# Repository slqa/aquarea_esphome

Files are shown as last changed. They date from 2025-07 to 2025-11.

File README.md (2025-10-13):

# Description
This project allows for controlling Aquarea F-series heat pumps directly from Home Assistant via standard ESPHome controls.
For it to function, special hardware is needed, which you will have to place between the remote control and the heat pump.
Thanks to this device, you are able to monitor heat pump states and issue your own commands.

```
  Heatpump RX ------|---|---/---------TX  REMOTE
           TX ------|   |   |         RX
            |       |   |   |         |
            |      RX  TX  RTS        |
            |      ESP12E             |
            |-------------------------|
```
I used hardware serial on pins GPIO15/GPIO13 and one pin for RTS from a GPIO5 Mini ESP board. In a 'normal' situation, the ESP12E only listens to communication between the remote and the heat pump, so you can have entity updates.
When you want to issue a state change from Home Assistant, the RTS pin is set, blocking communication from the remote to the heat pump. The ESP12E then sends the command and waits for confirmation.
After sending commands, it returns to the 'normal' state.
The Panasonic UART protocol has a baud_rate of 960, data_bits of 8, stop_bits of 1, parity of EVEN, and is inverted. My version of the bridge device realizes inversion at the hardware level, so there is no such setting in the YAML UART configuration.

Bridge PCB using ESP12E:
Brige schematic schematic

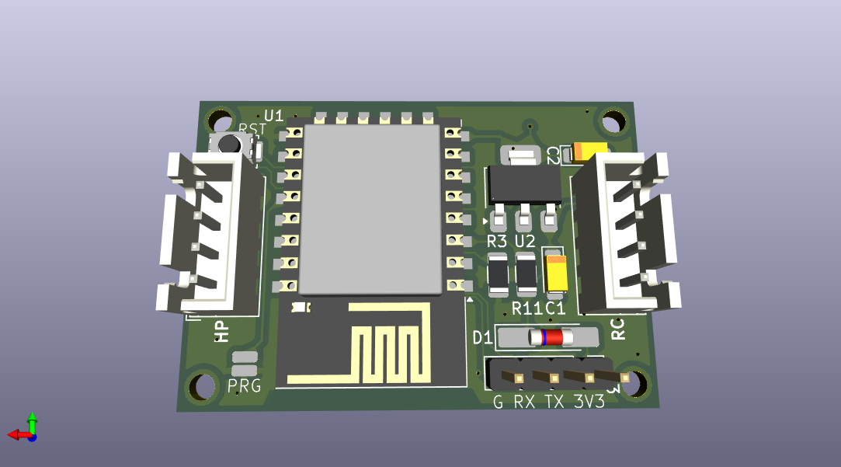
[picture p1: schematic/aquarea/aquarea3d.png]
Brige view view

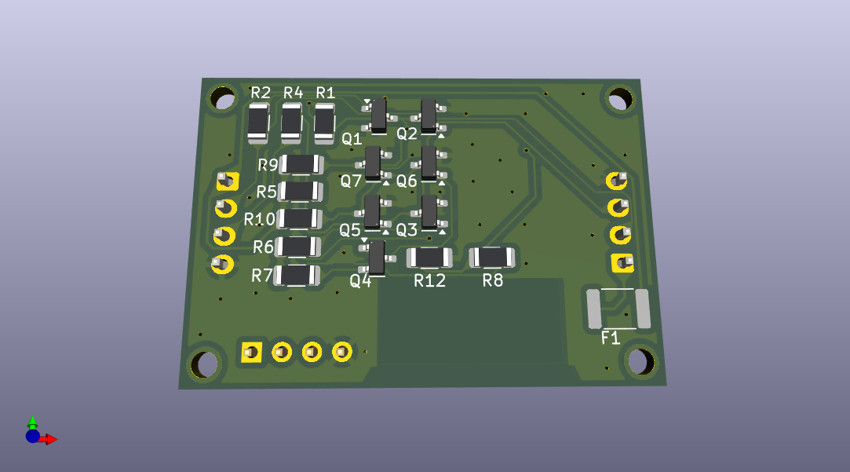
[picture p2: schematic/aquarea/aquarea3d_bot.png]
Brige view view_bottom


# How to use
Follow normal ESPHome steps
```bash
docker pull ghcr.io/esphome/esphome
docker run --rm -v "${PWD}":/config -it ghcr.io/esphome/esphome compile aquarea.yaml
docker run --rm -v "${PWD}":/config -it ghcr.io/esphome/esphome run aquarea.yaml
```

## 💾 Flashing Firmware via UART

Follow these steps to successfully flash your device's firmware using a UART adapter.

### 1. Wiring and Connection

Connect your **UART adapter** (or an ESP board with a USB level shifter) to the board's gold pin connector using the following pins:

| Pin | Function | Adapter Connection |
| :--- | :--- | :--- |
| **3.3V** | Power | Connect to **3.3V** on the adapter. |
| **TX** | Transmit | Connect to **RX** on the adapter. |
| **RX** | Receive | Connect to **TX** on the adapter. |
| **Gnd** | Ground | Connect to **Gnd** on the adapter. |

> ⚠️ **IMPORTANT:** If the PCB is still powered by the heat pump, **DO NOT CONNECT the 3.3V pin** from your adapter.

---

### 2. Entering Program Mode (Flash Mode)

To put the board into Flash Mode:

1.  **Short the PRG point:** Use a screwdriver or jumper wire to short the **PRG** test point (sometimes marked as old **SW1**).
2.  **Power Cycle:** While the **PRG** point is still shorted, quickly **power cycle** the PCB. You can do this by:
    * Disconnecting and immediately reconnecting the power **3.3V** pin.
    * Unplugging and replugging the main heat pump connector from the PCB.
    * Cycling the main power to the heat pump unit.
3.  **Release Short:** Once the power cycle is complete, **release the short** on the **PRG** point.

The device is now in **Flash Mode** and ready to accept new firmware.
# Home assistant entites

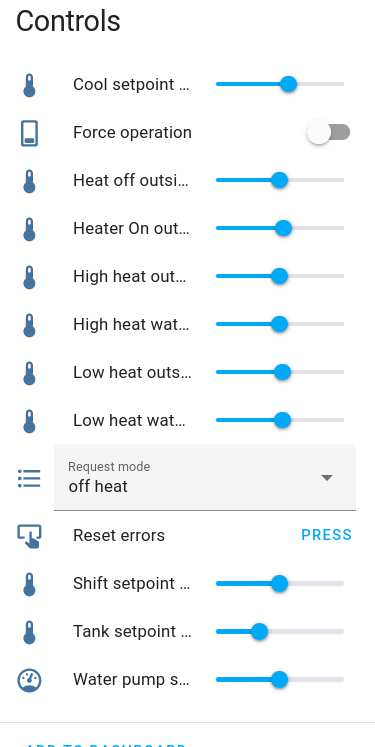
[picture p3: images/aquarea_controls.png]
Aquarea controls HA Controls

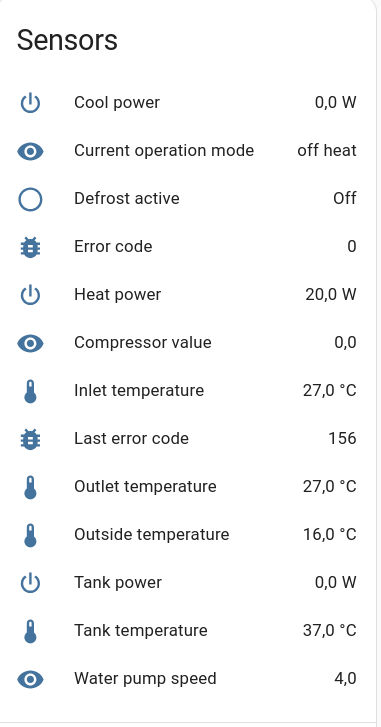
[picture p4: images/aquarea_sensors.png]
Aquarea sensors HA Sensors


# Thank you
Many thanks for work done by<br>
https://github.com/v-s-c-o-p-e/geisha_aquarea_panasonic_arduino_esp8266_proxy
https://github.com/pemue-git/pcb/tree/master/WH-MDC05F3E5_comm

## Disclaimer of Liability

THIS SOFTWARE IS PROVIDED "AS IS", WITHOUT WARRANTY OF ANY KIND, EXPRESS OR IMPLIED, INCLUDING BUT NOT LIMITED TO THE WARRANTIES OF MERCHANTABILITY, FITNESS FOR A PARTICULAR PURPOSE AND NONINFRINGEMENT. IN NO EVENT SHALL THE AUTHORS OR COPYRIGHT HOLDERS BE LIABLE FOR ANY CLAIM, DAMAGES OR OTHER LIABILITY, WHETHER IN AN ACTION OF CONTRACT, TORT OR OTHERWISE, ARISING FROM, OUT OF OR IN CONNECTION WITH THE SOFTWARE OR THE USE OR OTHER DEALINGS IN THE SOFTWARE.

You are solely responsible for any damage to your property, data, or third-party devices that results from the use or misuse of this software. By using this software, you agree to assume all risks associated with its use.

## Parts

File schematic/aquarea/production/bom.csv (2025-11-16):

Designator | Footprint | Quantity | Value | LCSC Part #
C1, C2 | CP_EIA-3216-10_Kemet-I_HandSolder | 2 | 10u
D1 | D_MiniMELF_Handsoldering | 1 | D_Schottky_Small
F1 | 1812 | 1 | 250mA
J1 | JST_XH_B4B-XH-A_1x04_P2.50mm_Vertical | 1 | RC_CABLE
J2 | JST_XH_B4B-XH-A_1x04_P2.50mm_Vertical | 1 | HP_CABLE
J3 | PinHeader_1x04_P2.54mm_Vertical | 1 | ESP_PROG
Q1, Q2, Q3, Q5, Q6, Q7 | SOT-23 | 6 | BC847
Q4 | SOT-23 | 1 | BC857
R1, R11, R3, R4, R6, R7 | 1206 | 6 | 1k
R10, R12, R2, R8, R9 | 1206 | 5 | 10k
R5 | 1206 | 1 | 20k
SW1 | 0508 | 1 | Flash
SW2 | SW_Push_SPST_NO_Alps_SKRK | 1 | RESET
U1 | ESP-12E | 1 | ESP-12E
U2 | SOT-223-3_TabPin2 | 1 | AMS1117-3.3

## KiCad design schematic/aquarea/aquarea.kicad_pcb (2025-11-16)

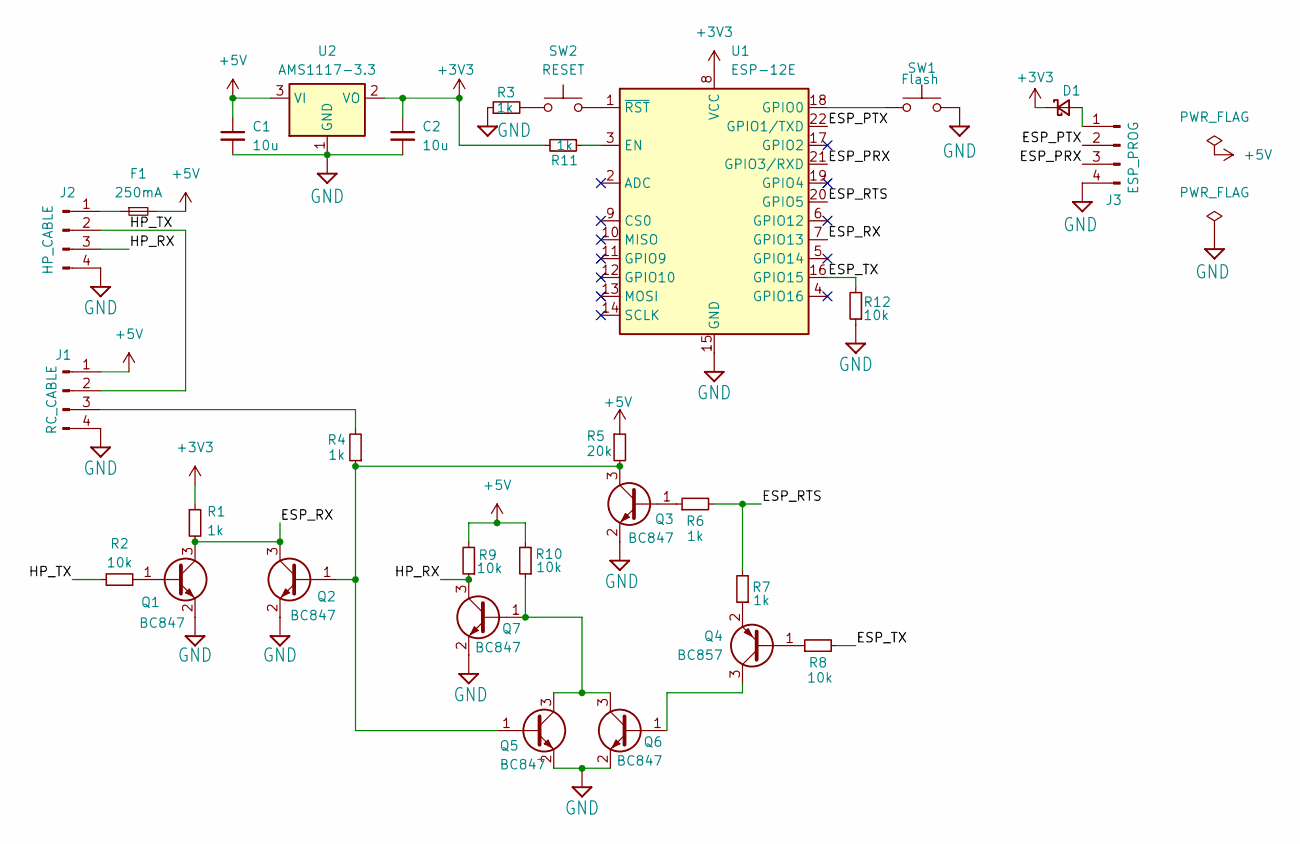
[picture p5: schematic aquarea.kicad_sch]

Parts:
C1, C2: 10u; CP_EIA-3216-10_Kemet-I_HandSolder
D1: D_Schottky_Small; D_MiniMELF_Handsoldering
F1: 250mA; Fuse_1812_4532Metric
J1: RC_CABLE; JST_XH_B4B-XH-A_1x04_P2.50mm_Vertical
J2: HP_CABLE; JST_XH_B4B-XH-A_1x04_P2.50mm_Vertical
J3: ESP_PROG; PinHeader_1x04_P2.54mm_Vertical
Q1, Q2, Q3, Q5, Q6, Q7: BC847; SOT-23
Q4: BC857; SOT-23
R1, R3, R4, R6, R7, R11: 1k; R_1206_3216Metric
R2, R8, R9, R10, R12: 10k; R_1206_3216Metric
R5: 20k; R_1206_3216Metric
SW1: Flash; R_0508_1220Metric
SW2: RESET; SW_Push_SPST_NO_Alps_SKRK
U1: ESP-12E
U2: AMS1117-3.3; SOT-223-3_TabPin2

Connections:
+3V3: C2.1, D1.1 (K), R1.1, R11.2, U1.8 (VCC), U2.2 (VO)
+5V: C1.1, F1.2, J1.1, R5.1, R9.2, R10.2, U2.3 (VI)
/ESP_PRX: J3.3, U1.21 (GPIO3/RXD)
/ESP_PTX: J3.2, U1.22 (GPIO1/TXD)
/ESP_RTS: R6.2, R7.2, U1.20 (GPIO5)
/ESP_RX: Q1.3 (C), Q2.3 (C), R1.2, U1.7 (GPIO13)
/ESP_TX: R8.2, R12.2, U1.16 (GPIO15)
/HP_RX: J2.3, Q7.3 (C), R9.1
/HP_TX: J1.2, J2.2, R2.1
GND: C1.2, C2.2, J1.4, J2.4, J3.4, Q1.2 (E), Q2.2 (E), Q3.2 (E), Q5.2 (E), Q6.2 (E), Q7.2 (E), R3.1, R12.1, SW1.2, U1.15 (GND), U2.1 (GND)
unnamed: D1.2 (A), J3.1
unnamed: J1.3, R4.2
unnamed: F1.1, J2.1
unnamed: Q1.1 (B), R2.2
unnamed: Q2.1 (B), Q3.3 (C), Q5.1 (B), R4.1, R5.2
unnamed: Q3.1 (B), R6.1
unnamed: Q4.1 (B), R8.1
unnamed: Q4.3 (C), Q6.1 (B)
unnamed: Q4.2 (E), R7.1
unnamed: Q5.3 (C), Q6.3 (C), Q7.1 (B), R10.1
unnamed: R3.2, SW2.1
unnamed: R11.1, U1.3 (EN)
unnamed: SW1.1, U1.18 (GPIO0)
unnamed: SW2.2, U1.1 (~RST)

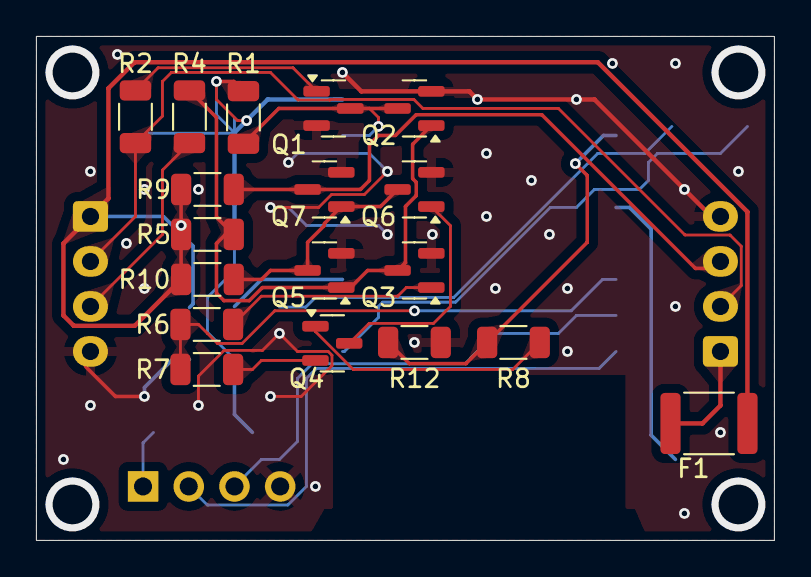
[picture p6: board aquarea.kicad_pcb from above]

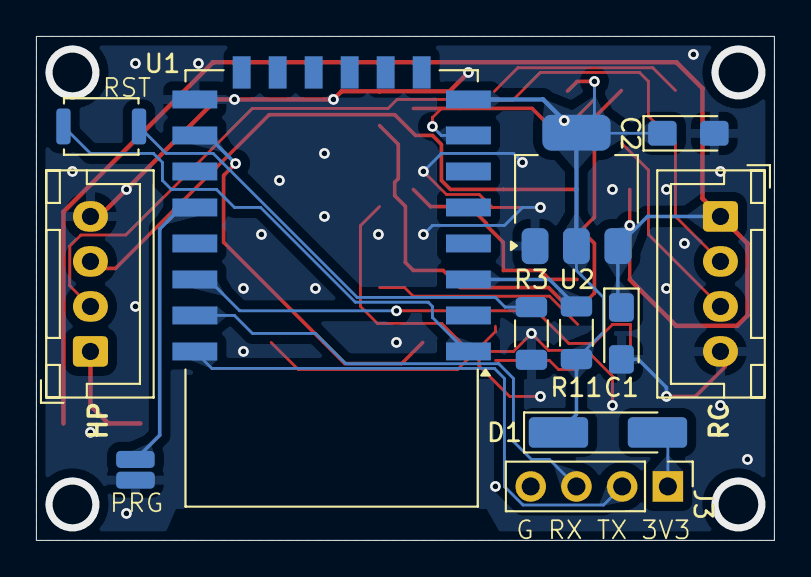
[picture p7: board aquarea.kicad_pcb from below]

Board: 2 copper layers, 41.0 x 28.0 mm, 30 parts (12 on the bottom side), 24 nets.

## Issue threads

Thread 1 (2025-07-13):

Photo

elvisquaglia, 2025-07-13:
Hi, can you post the photo with the wire connections betwen remote and d1 mini?

slqa, 2025-07-13:
I have to reverse engineer my board, because I lost schematic. In case D1 Mini there is need for level shifting of HeatPump/Remote lines, D1 can't handle 5V, so schematic is more complicated.
I used as reference this schematic
https://github.com/pemue-git/pcb/tree/master/WH-MDC05F3E5_comm

slqa, 2025-07-18:
Yes, you have to have special hardware.
You can use schematic from here  https://github.com/pemue-git/pcb/tree/master/WH-MDC05F3E5_comm
Mine is little bit simpler, but code it should work fine with either of them.

gytisgreitai, 2025-07-18:
ok, and how do you wire this to the pump? As I understand this one is for monoblock, not split type?

gytisgreitai, 2025-07-18:
Ok, thanks for support, and sorry for dumb questions this PCB https://github.com/pemue-git/pcb/tree/master/WH-MDC05F3E5_comm lists OR-FB, OR-WP, BR-FB pins besides +5v/GND.
My remote (indoor split unit) has TX/RX/+5v/GND . So I'm kind of lost what's the connection path (unless it does not work with split one?)

slqa, 2025-07-18:
Basic idea is that you split TX, so you have 2 wires

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

 marked there. So in normal situation communication goes from Remote to Heatpump, but when you want send something, you block TX from Remote via RTS pin, and it connects D1 TX to normal TX path.
RX is intact since it goes from motherboard, so you only monitor it.
I didn't cut cable, I bought connectors and I have cable from heatpump connected, and my cable goes to remote. D1 is powered from 5V.

gytisgreitai, 2025-07-19:
Ok, I think I finally go it - the short labels are colours in german - can you confirm this is correct?
I'm not sure about RX<->TX (D7 and D8) from D1 mini . Should they be reversed ?

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

Also, the ascii schematic on the README, shouldn't it be more like this:
```
  Heatpump RX ----------|---/---------TX  REMOTE
           TX ------|   |   |         RX
            |       |   |   |         |
            |      RX  TX  RTS        |
            |      D1_Mini            |
            |-------------------------|
```

slqa, 2025-07-19:
Communication between HP and RC is like, RC will constantly ask HP about values of registers. RC sends on its TX request, and then HP receives it on its RX. Response is like HP sends on its TX, and RC recieves on its RX.
So to have sensors updates from HP you intercepts HP TX. And to be able to sends your commands, you have to cut off RC TX, and inject your command from D1 mini TX to HP RX.
So, if you marked Remote uart, you have to have in wires hooked up to D1 mini in opposite way.
 Also RTS is connected to pin D1, not to RST of D1 mini.

Regarding ASCII, yes code works like your version (only checks HP TX), but I had also RC TX connected, to be able to checks other registers.

slqa, 2025-07-19:
Ok, wire colors are correct only lables are opposite. Sorry, I didn't think that you are referring to lables from RC connector, they mark them opposite in RC.
Brown is HP TX, RC RX.
orange is HP RX, RC TX.

gytisgreitai, 2025-07-19:
Thanks!
The picture is from RC connector back, and orange there is labeled RX* :)
I now probably understand why the schematic uses colour codes, cause it's easy to get lost about TX/RX depending on which side you look from.

So this should be the correct version ?:

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

What about connectors, do you have an id/link for those ? I don't want to splice the cable, rather make the socket/connector :)

slqa, 2025-07-30:
I see that HP RX on diagram should be HP TX :) Panasonic UART is inverted, so idle is low, and transistors are cut off during idle. And one thing worth noticing, in my case, UART is D1 is in normal mode, so inversion is done on transistors.
It maybe a case that for other "spy" boards, like one which mentiond before, there will be need for adding inversion flag to yaml.

gytisgreitai, 2025-08-10:
one more question: `My version of the bridge device realizes inversion at the hardware level, so there is no such setting in the YAML UART configuration.` <- so if I use the hardware version from https://github.com/pemue-git/pcb/tree/master/WH-MDC05F3E5_comm - do I need to invert this in the esphome config?

slqa, 2025-08-10:
I think so, I never tried it, but in other project which I used as reference https://github.com/v-s-c-o-p-e/geisha_aquarea_panasonic_arduino_esp8266_proxy there is inversion set in serial config.

gytisgreitai, 2025-08-11:
so for RX nothing is needed, TX does not seem to work, but perhaps that's just my soldering skills, will test further. Anyway - thanks for this library and support. Really great to see my heatpump in hass

Closed 2025-08-17.

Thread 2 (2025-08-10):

Support for Booster status & Setting Tank target temperature?

gytisgreitai, 2025-08-10:
Hey,

is there an option to get booster status ? As I understand that this is 198 register https://github.com/der-lolo/aquarea/blob/master/FHEM/67_Aquarea.pm#L641C5-L645 ?

And another one: is it possible to control tank target temperature?

Thanks!

slqa, 2025-08-12:
Regarding tank, there is tank setpoint entity for tank temperature.
Booster in register 198 is only setting, but I see I made a comment that register 17 should carry such information.
https://github.com/slqa/aquarea_esphome/blob/main/components/aquarea/aquarea.hpp#L24-L68
I recall that I didn't test it, because it's not so simple to trigger booster heater, but it shouldn't be a lot of work to add it.

Closed 2025-08-17.

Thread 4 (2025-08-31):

Low heat water temperature adjustable from 30°C to 55°C.

roadrunner1910, 2025-08-31:
Hello,

thank you for all your work.

the low heat water temperature can only be set from 30°C to 50°C. On the remote, it can be set from 25°C to 55°C.
This setting is needed for our house.

BR

slqa, 2025-09-01:
Hello,

I must go with my house approach, but it is simple change :D
I did my pcb on universal pcb, so it isn't pretty, best option will be to have smd board. Maybe I will be able to adapt schematic from https://github.com/pemue-git/pcb/tree/master/WH-MDC05F3E5_comm to esp.

BR

roadrunner1910, 2025-09-06:
That’s wonderful. Let me know, because I may purchase more boards for my German community.

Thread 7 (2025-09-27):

Read working, not write

gytisgreitai, 2025-09-27:
Hey,

do you have any tips of how to troubleshoot heatpump not accepting commands. Logs only show:

```
[10:23:39][D][aquarea:272]: rts high
[10:23:39][D][aquarea:331]: send: 90 3
[10:23:39][D][aquarea:284]: rts low, timeout
[10:23:39][W][component:257]: Component aquarea took a long time for an operation (306 ms).
[10:23:39][W][component:258]: Components should block for at most 30 ms.
```
I used the board from https://github.com/pemue-git/pcb/tree/master/WH-MDC05F3E5_comm
RST wired on D1 pin

Thanks !

slqa, 2025-09-27:
Hello,

I would suspect wrong uart levels when esp transmits. If connecting pcd in middle of communication doesn't break hp-rc communication, and you can see proper values in HA, it most likely mean that esp tx idle state doesn't invert correctly on hp rx pin.
What I did for troubleshooting, I created simple esphome project with 3 pins which we use as gpio switch. Then I connected pcb, and you can check what happens on hp rx pin.
When rts is low any change in esp tx gpio should not change hp rx, only connecting rc tx either to gnd and vcc should change it.
When rts is high, esp tx high, hp rx should be low, esp tx low, hp rx should be high. And with rts low, if you will change rc tx state, hp rx shouldn't change.
Hope it make sense

BR

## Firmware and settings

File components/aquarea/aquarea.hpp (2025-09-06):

#pragma once

#include <array>
#include <functional>
#include <vector>
#include <cstdint>
#include <queue>
#include "esphome/core/hal.h"
#include "esphome/core/gpio.h"
#include "esphome/core/component.h"
#include "esphome/core/log.h"
#include "esphome/components/sensor/sensor.h"
#include "esphome/components/text_sensor/text_sensor.h"
#include "esphome/components/binary_sensor/binary_sensor.h"
#include "esphome/components/button/button.h"
#include "esphome/components/switch/switch.h"
#include "esphome/components/number/number.h"
#include "esphome/components/select/select.h"
#include "esphome/components/uart/uart.h"

namespace esphome {
namespace aquarea {

enum Registers
{
  Defrost = 17, // -> 0x02 booster
  OutsideTemp = 18,
  OutletTemp = 19,
  ErrorCode =  20,
  InletTemp = 21,
  TankTemp  =  22,
  Compressor = 23,
  LastErrorCode = 24,
  Mode = 27,
  HeatLSB = 29,
  HeatMSB = 30,
  CoolLSB = 31,
  CoolMSB = 32,
  TankLSB = 33,
  TankMSB = 34,
  PumpStage = 35,
  Force = 128, //-> 0x40
  ResetError = 129,
  HeatOutsideTempLow = 130,
  HeatOutsideTempHigh = 131,
  HeatWaterTempLow = 132,
  HeatWaterTempHigh = 133,
  HeatOffOutsideTemp = 134,
  HeaterOnOutsideTemp = 135,
  CoolSetpointTemp = 136,
  TankSetpointTemp = 137,
  ShiftSetpoint = 138,
  ServiceMode = 142, // 0x02 - pump speed
  ReqMode = 144,
  PumpSpeed = 147,
  // Settings 192; // -> 0x1 room thermo, 0x80, anitfreeze, 0x04 solar prio, 0x40 cool prio, 0x08 heat prio, 0x10 steril
  // HeatInterval 193; // -> 1 == 30min, 20 == 10h
  // TankInterval 194; // in min
  // BoosterDelay 195; // in min
  // SterilTemp 196;
  // SterilTime 197; // in min
  // SettingsCont 198; // -> 0x04 booster, 0x08 bpan
  // AutoToCoolTemp 199;
  // AutoToHeatTemp 200;
  // UnknownCommand 255;
  Num
};

std::array<std::function<void(uint8_t value)>, (size_t)Registers::Num> registers;

class AquareaComponent : public Component, public uart::UARTDevice
{
public:
    AquareaComponent() = delete;
    AquareaComponent(InternalGPIOPin *rts_pin_)
    {
      rx_packet.reserve(4);
      rts_pin = rts_pin_;
    }

protected:
    SUB_BINARY_SENSOR(defrost);
    SUB_BINARY_SENSOR(booster);
    SUB_SENSOR(outside_temperature);
    SUB_SENSOR(outlet_temperature);
    SUB_SENSOR(inlet_temperature);
    SUB_SENSOR(tank_temperature);
    SUB_SENSOR(compressor_value);
    SUB_SENSOR(heat_power);
    SUB_SENSOR(cool_power);
    SUB_SENSOR(tank_power);
    SUB_SENSOR(pump_speed);
    SUB_TEXT_SENSOR(error_code);
    SUB_TEXT_SENSOR(last_error_code);
    SUB_TEXT_SENSOR(current_mode);
    SUB_BUTTON(reset_error);
    SUB_SWITCH(force);
    SUB_NUMBER(heat_out_temp_low);
    SUB_NUMBER(heat_out_temp_high);
    SUB_NUMBER(heat_water_temp_low);
    SUB_NUMBER(heat_water_temp_high);
    SUB_NUMBER(heat_off_out_temp);
    SUB_NUMBER(heater_on_out_temp);
    SUB_NUMBER(cool_setpoint_temp);
    SUB_NUMBER(tank_setpoint_temp);
    SUB_NUMBER(shift_setpoint_temp);
    SUB_NUMBER(pump_speed);
    SUB_SELECT(request_mode);

  std::queue<std::pair<uint8_t /*register*/, uint8_t /* value */>> write_queue;
private:
  struct Power
  {
    void write_lb(long timestamp, uint8_t value)
    {
      valid = false;
      lb_timestamp = timestamp;
      power=value;
    }

    void write_mb(long timestamp, uint8_t value)
    {
      power |= ((uint16_t)value)<<8;
      if((timestamp - lb_timestamp) < 200) valid = true;
    }

    bool is_valid() const
    {
      return valid;
    }

    uint16_t get_power() const
    {
      return power;
    }

  private:
    long lb_timestamp = 0;
    uint16_t power=0u;
    bool valid=false;
  };

  std::string get_current_mode(uint8_t value)
  {
    std::string mode(value & 1 ? "on" : "off");
    if (value & 2) mode += " heat";
    if (value & 4) mode += " cool";
    if (value & 16) mode += " tank";
    if (value & 32) mode += " auto";
    if (value & 64) mode += " quiet";
    if (value & 128) mode += " heater";

    return mode;
  }

  void register_select_if_present(const Registers& reg, select::Select* select, std::function<std::string(uint8_t value)> modifier = {})
  {
    if(select)
      registers[reg] = std::move([select = select, modifier = std::move(modifier)](uint8_t value)
        { 
          select->publish_state(modifier ? modifier(value) : std::to_string((uint32_t)value));
        });
  }

  void register_text_sensor_if_present(const Registers& reg, text_sensor::TextSensor* text_sensor, std::function<std::string(uint8_t value)> modifier = {})
  {
    if(text_sensor)
      registers[reg] = std::move([text_sensor = text_sensor, modifier = std::move(modifier)](uint8_t value)
        { 
          text_sensor->publish_state(modifier ? modifier(value) : std::to_string((uint32_t)value));
        });
  }

  void register_binary_sensor_if_present(const Registers& reg, const std::vector<std::pair<binary_sensor::BinarySensor* /*sensor*/, uint8_t /*mask*/>>& sensors)
  {
    if(std::any_of(sensors.begin(), sensors.end(), [](auto& sensor){return sensor.first != nullptr;}))
      registers[reg] = std::move([&](uint8_t value)
        { 
          for(auto& sensor : sensors)
          {
            if(sensor.first)
              sensor.first->publish_state(value & sensor.second);
          }
        });
  }

  void register_sensor_if_present(const Registers& reg, sensor::Sensor* sensor, std::function<uint8_t(uint8_t value)>&& modifier = {})
  {
    if(sensor)
      registers[reg] = std::move([sensor = sensor, modifier = std::move(modifier)](uint8_t value)
        { 
          if(modifier)
            value = modifier(value);
          sensor->publish_state(*((int8_t*)&value));
        });
  }

  void register_power_sensor_if_present(const Registers& reg_lsb, const Registers& reg_msb, sensor::Sensor* sensor, Power& power)
  {
    if(sensor)
    {
      registers[reg_lsb] = std::move([&power](uint8_t value)
        { 
          power.write_lb(millis(), value);
        });
      registers[reg_msb] = std::move([&power, sensor = sensor](uint8_t value)
        { 
          power.write_mb(millis(), value);
          if(power.is_valid())
            sensor->publish_state(power.get_power());
        });
    }
  }

  void register_switch_if_present(const Registers& reg, switch_::Switch* sw, std::function<uint8_t(uint8_t value)> modifier = {})
  {
    if(sw)
      registers[reg] = std::move([sw = sw, modifier = std::move(modifier)](uint8_t value)
        { 
          sw->publish_state(modifier ? modifier(value) : value);
        });
  }

  void register_number_if_present(const Registers& reg, number::Number* number, std::function<uint8_t(uint8_t value)> modifier = {})
  {
    if(number)
      registers[reg] = std::move([number = number, modifier = std::move(modifier)](uint8_t value)
        { 
          if(modifier) 
            value = modifier(value);
          number->publish_state(*((int8_t*)&value));
        });
  }
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

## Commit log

2025-07-18 Add brige schematic
2025-08-02 Schematic correction and readme update
2025-08-12 Add support for booster heater binary sensor
2025-09-05 Add aplha schematics for proxy device
    [aquarea.kicad_pcb, aquarea.kicad_sch]
2025-09-13 Update schematic andpcb after tests; add bom and gerbers
    [aquarea.kicad_pcb, aquarea.kicad_sch, bom.csv]
2025-09-13 Update schematic
    [aquarea.kicad_pcb, aquarea.kicad_sch, bom.csv]
2025-10-13 Update README.md - uart flashing
2025-11-16 Add proper reset handling and optimize design adround antenna
    [aquarea.kicad_pcb, aquarea.kicad_sch, bom.csv]
2026-02-28 Set RTS pin mode to output in setup
